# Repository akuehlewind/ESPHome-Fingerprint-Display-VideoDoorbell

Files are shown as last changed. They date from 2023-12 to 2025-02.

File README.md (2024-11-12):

# ESPHome-Doorbell using Aqara G4 inside the case enriched with a Grow R503 fingerprint sensor and 2.8 ILI9341 display

Video doorbell (using Aqara G4) for [Home Assistant](https://www.home-assistant.io) and [ESPHome](https://www.esphome.io). 
It integrates a Grow R503 fingerprint sensor to open a door (in my case a NUKI door lock) via HomeAssistant and additionally I added an ILI9341 display to show some status information like temperature, closed window indicator and most importantly some messages. I can set some messages in a text sensor in HomeAssistant to show them on the display, e.g. to tell the delivery person to just leave the package in the garage. The Aqara is independent of the fingerprint and the display and is only integrated into the housing to make it look nice. The Aqara G4 is simply added via Homekit.

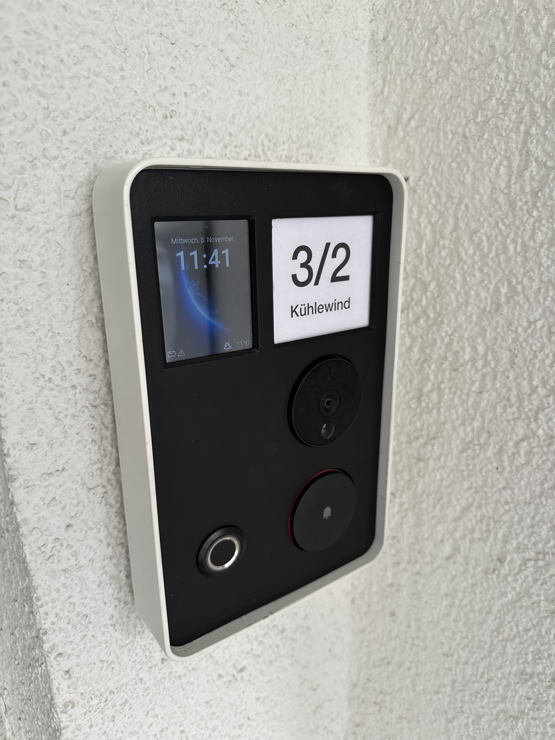
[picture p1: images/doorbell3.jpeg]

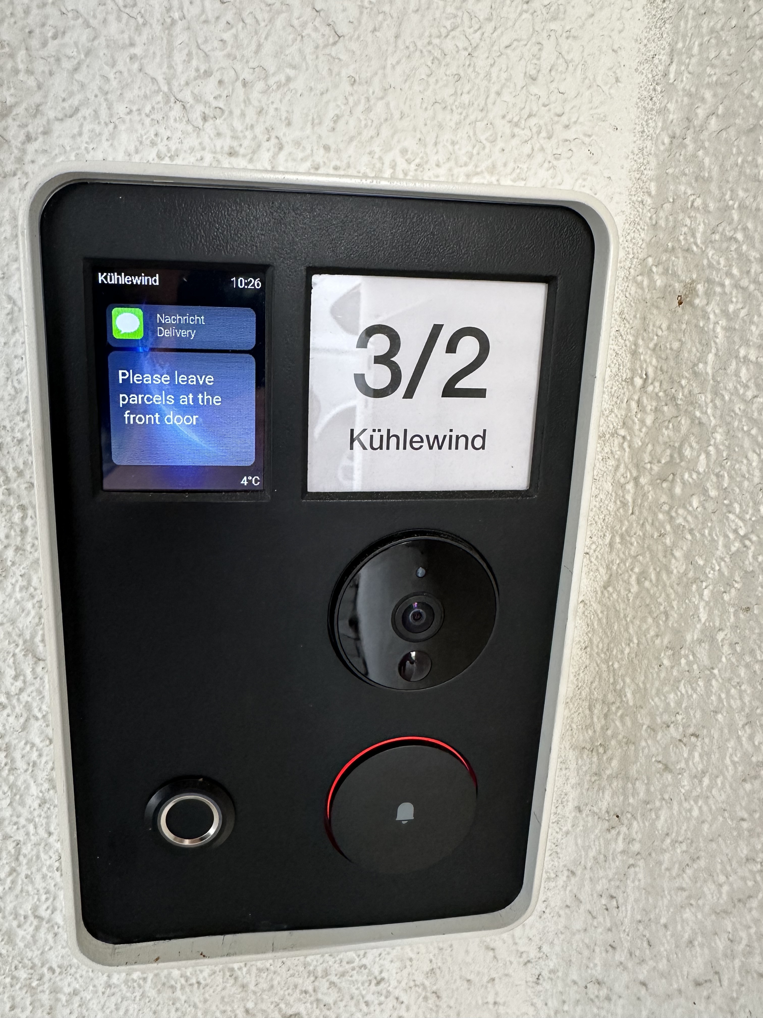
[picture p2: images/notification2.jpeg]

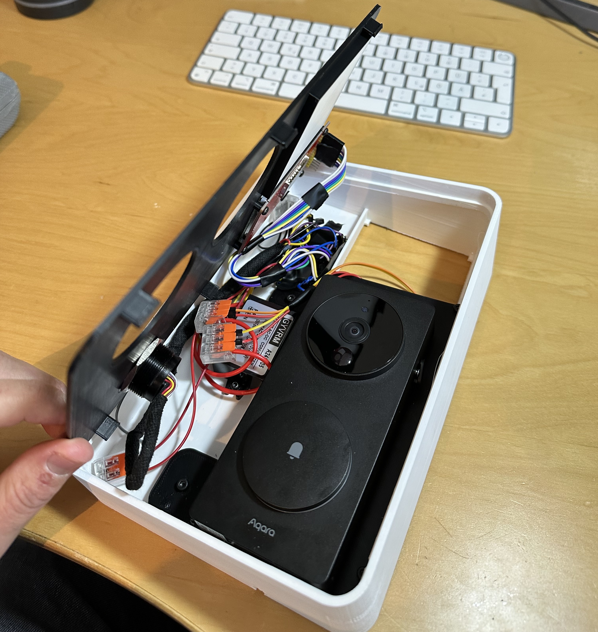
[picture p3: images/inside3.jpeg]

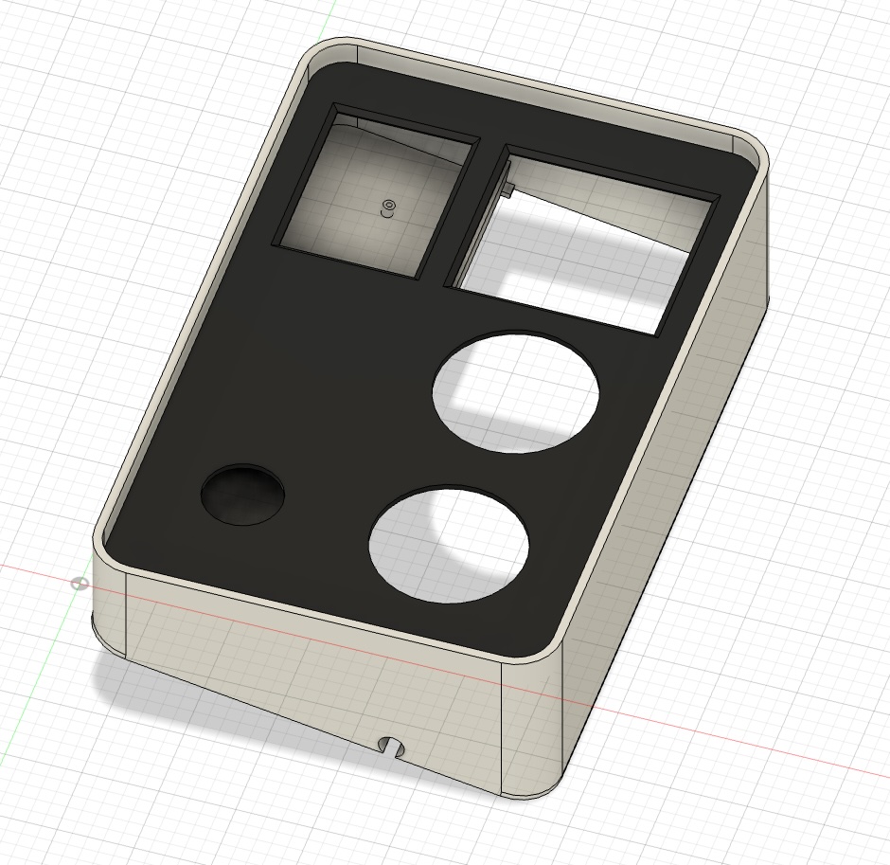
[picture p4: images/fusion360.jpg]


### Features:

- Aqara G4 Videodoorbell as doorbell which I integrated in the case
- Fingerprint Sensor Grow R503 to trigger actions like door opening or you can use it as doorbell
- Display to show some status infos and messages
- Using [ESPHome](https://www.esphome.io) which makes it easy to code and modify for your needs

## Parts needed

| Part | Price | Comment |
|---|---|---|
| Aqara G4 | 90$ | Aqara G4 Homekit Cam |
| Grow R503 | 15$ | Get one from AliExpress 					 |
| ILI9341					 | 15$ | 2.8" 					 |
| ACDC Converter (in my case)  | 5$ | I had some 15V AC wire available so I used an ACDC converter to run the ESP with 5V |

## How
- Flash your ESP32 via ESPHome and use the yaml from the esphome folder. Adjust to your needs
- Print the parts. 
- Use a few screws to attach the display and the Aqara Mount Plate
- Solder the connections or just use some pin connectors and WAGO connectors
- Assemble 

## HomeAssistant
- Create some helpers in home assistant with the following types

| ID | Type | Comment |
|---|---|---|
| input_text.doorbell_text | text | Notification text. Use "," to terminate each line ie. "Leave parcels,outside," (set value without quotation marks)|
| input_text.doorbell_headline | text | Headline of notification. |
| input_text.doorbell_subheadline | text | Sub-Headline of notification. |
| input_boolean.doorbell_display_mailbox_notification | switch  | Doorbell Display Mailbox Notification |

## Connections
Follow the connection diagram, which shows how to put everything together.

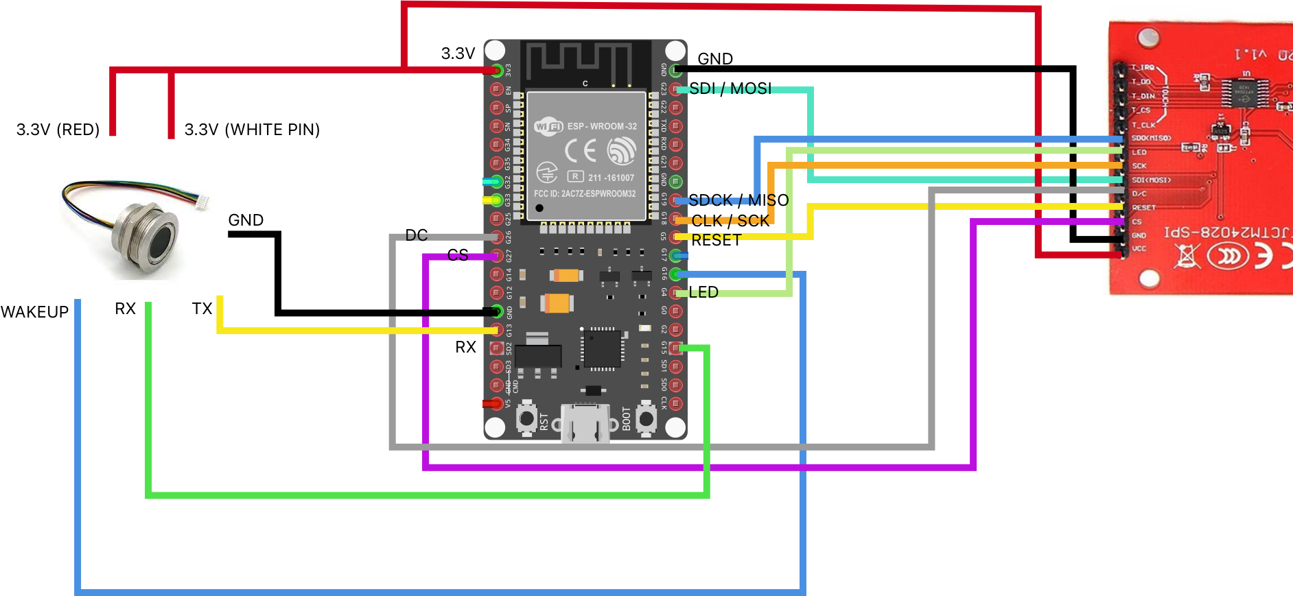
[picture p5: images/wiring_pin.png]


| Glow R5 | PIN  ESP32 | Comment |
|---|---|---|
| TX | G13 | Yellow (RX & TX are twisted) |
| RX | G15 | Green (RX & TX are twisted) 	 |
| GND 					 | GND | Obvious 					 |
| WAKEUP | G16 | Sensing PIN |
| 3.3V | 3.3V | Red |
| 3.3VT | 3.3V | White |

| ILI9341 | PIN  ESP32 | Comment |
|---|---|---|
| CS | G27 | CS |
| D/C | G26 | DC |
| RESET | G5 | RESET |
| SCK | G18 | Clock PIN, CLK |
| SDI (MOSI) | G23 | SDI |
| SDOK (MISO) | G19 | SDOK (MISO) |
| LED | G4 | LED Backlight |
| GND | GND | Ground |
| VCC | 3.3V | Power |\

## 3D Print
See folder print to get all SLT files and the fusion360 file. Feel free to adjust and remix\

# DISCLAIMER
This project is to be considered as a work in progress. 
In my case I have a Siedle doorbell mounted outside and its not my house - so the case has some cut out on the backside that just fits perfectly over the existing Sidle doorbell.
So I just covered the old doorbell and used the power connection from it. As doorbell I now use the Aqara G4 (Homekit) and just added the fingerprint and display for fun to enter my house and show some messages.
Feel free to adjust and remix the 3D cover to your needs. Its designed in Fusion 360 (see folder fusion360)

## Other
Example screenshot of notification



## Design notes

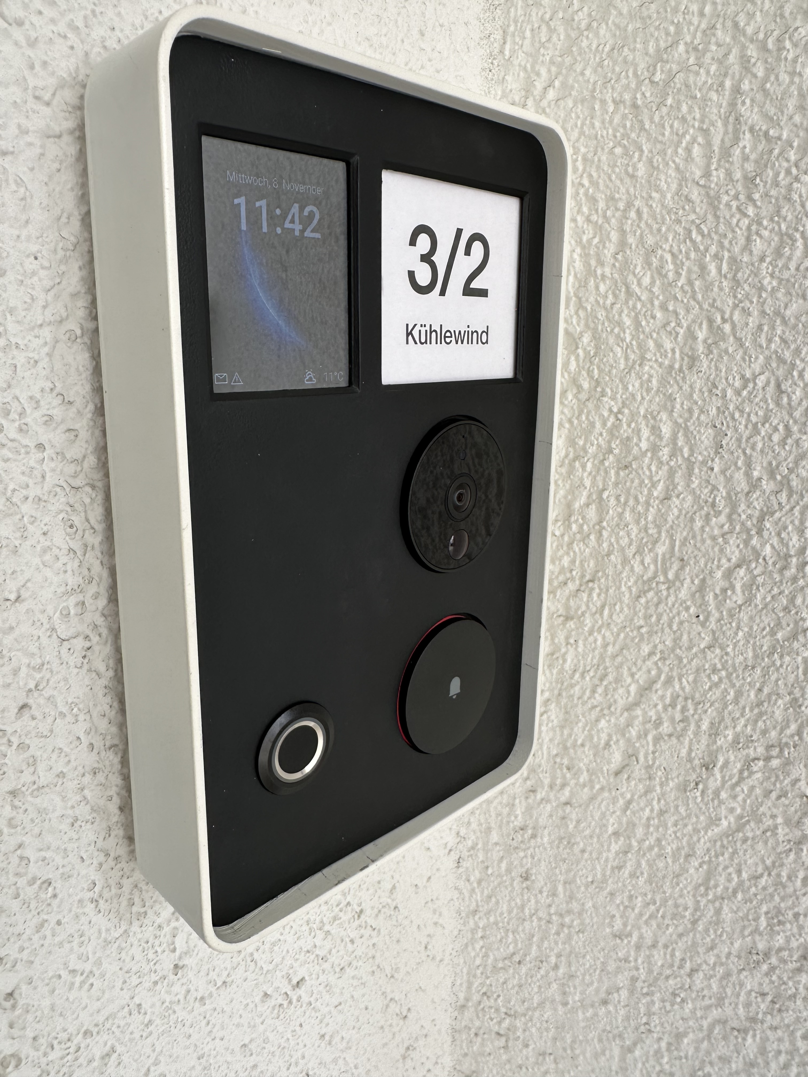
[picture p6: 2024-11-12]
images/doorbell2.jpeg

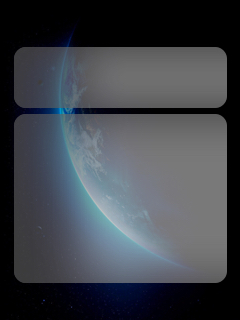
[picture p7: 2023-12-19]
esphome/images/doorbell-background-notification.jpg

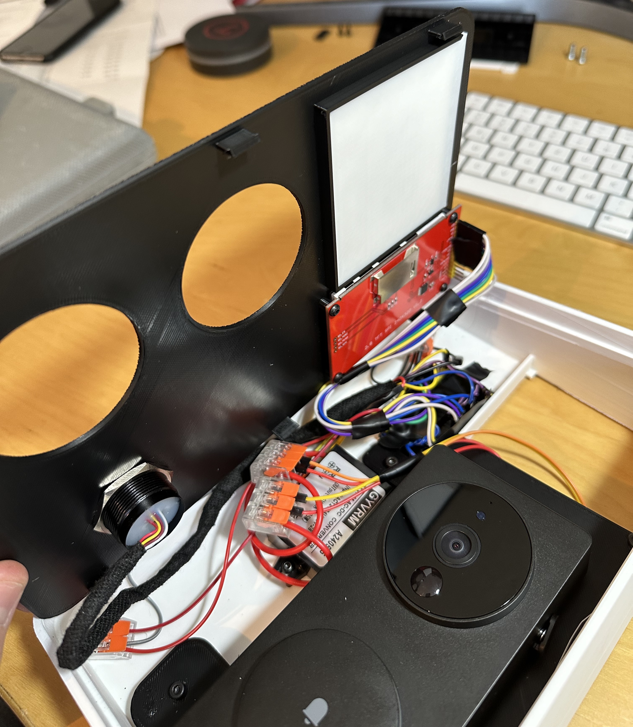
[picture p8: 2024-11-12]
images/inside2.jpeg

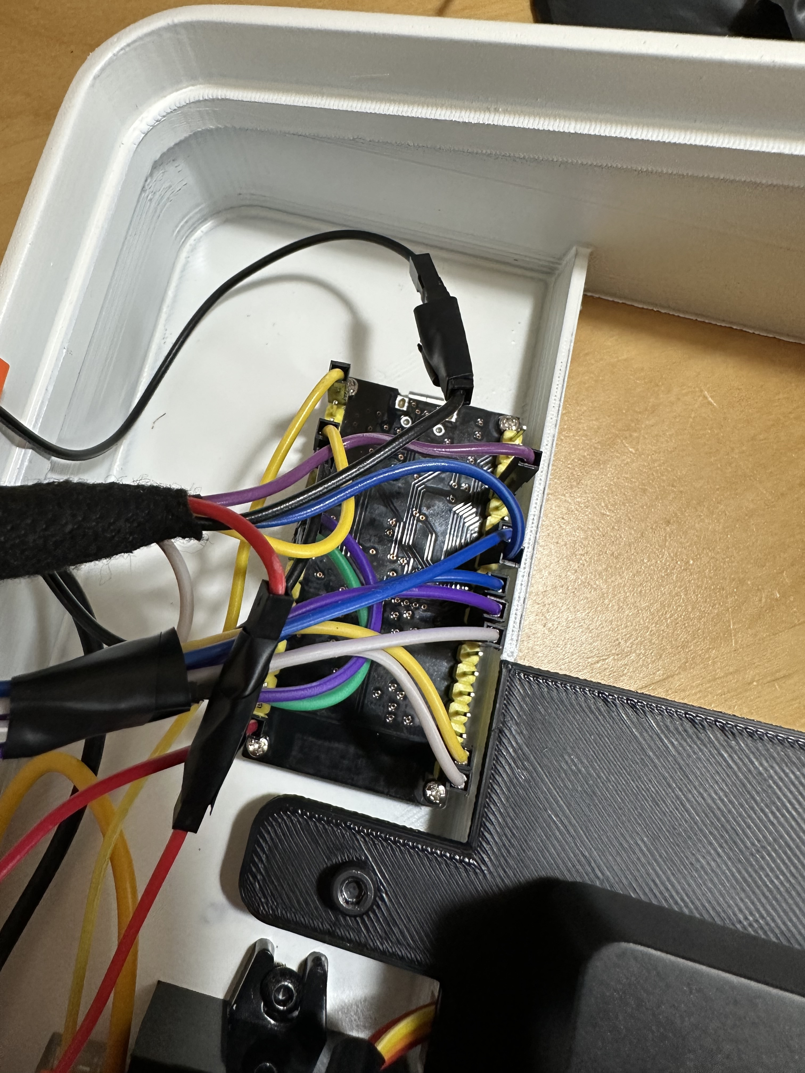
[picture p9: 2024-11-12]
images/esp32.jpeg

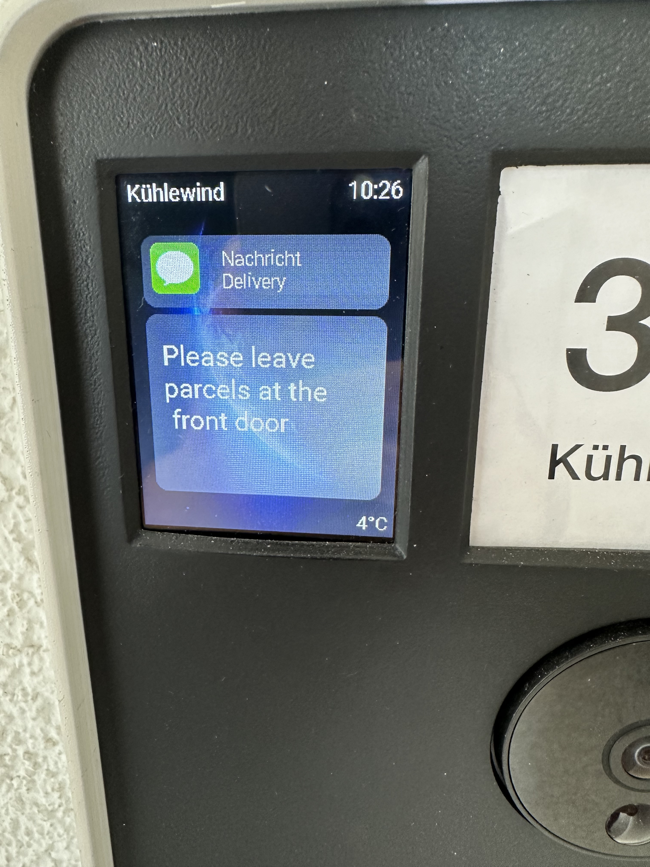
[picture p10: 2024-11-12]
images/notification3.jpeg

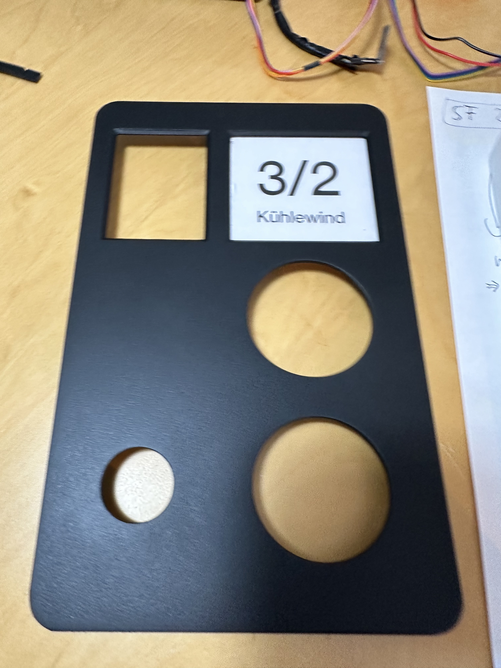
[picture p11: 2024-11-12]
images/frontcover.jpeg

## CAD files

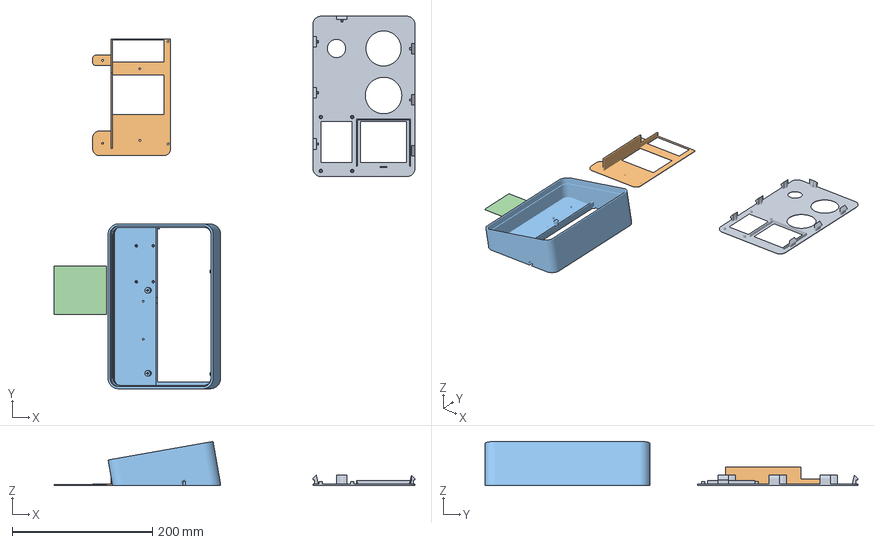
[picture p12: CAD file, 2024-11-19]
3d_print/case.3mf
514.3 x 530.9 x 62.9 mm
cover.stl
aqara-mount-plate.stl
case.stl
sign-backplate.stl

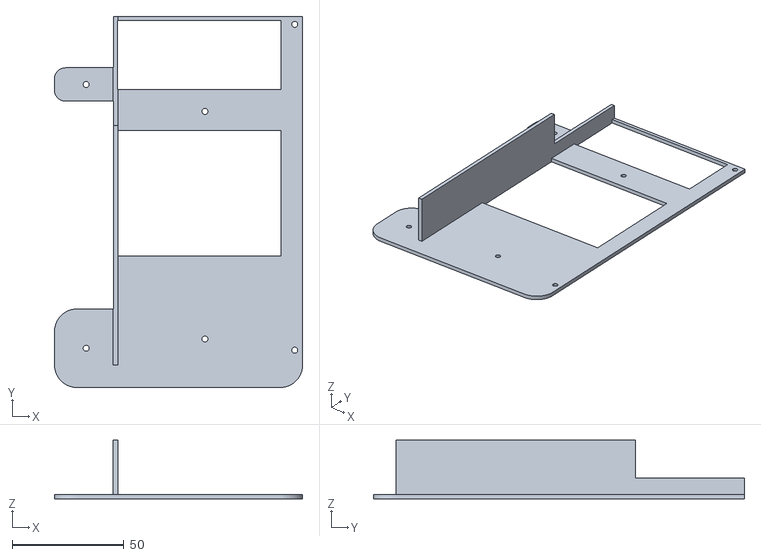
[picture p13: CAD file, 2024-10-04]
3d_print/aqara-mount-plate.stl
111.3 x 166.3 x 26.3

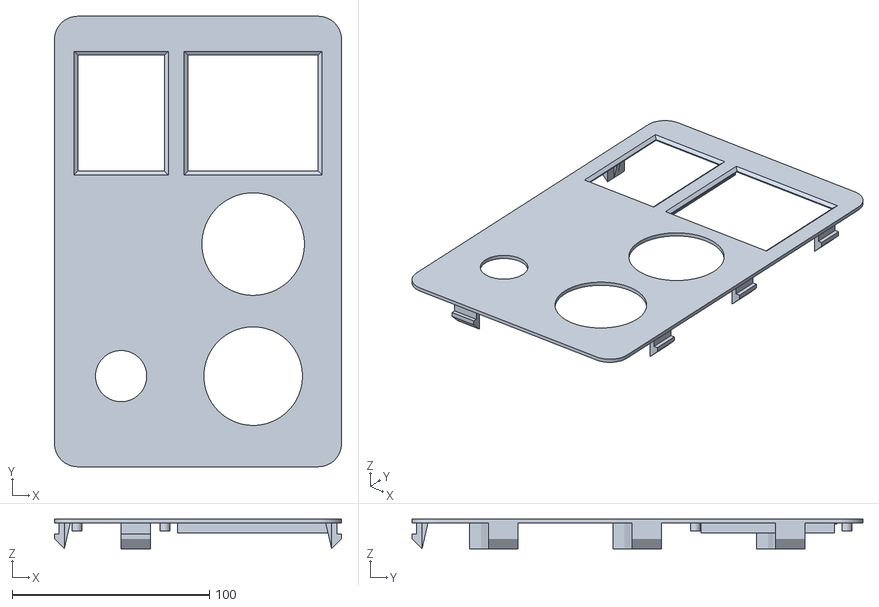
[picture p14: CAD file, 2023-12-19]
3d_print/cover.stl
145.6 x 228.6 x 15.0

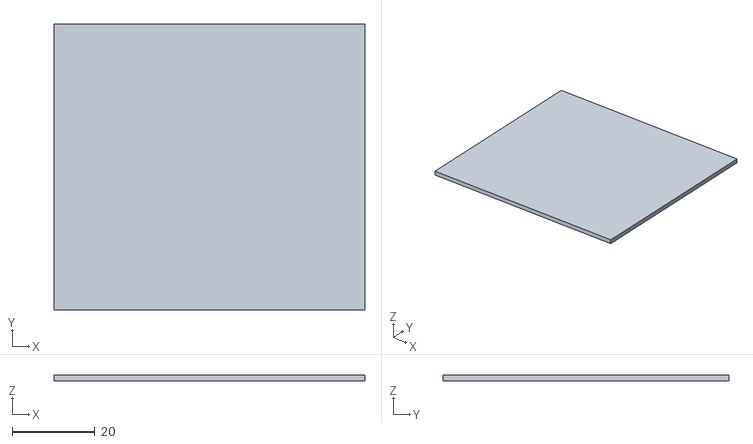
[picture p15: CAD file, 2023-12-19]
3d_print/sign-backplate.stl
75.0 x 69.0 x 1.50

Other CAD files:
3d_print/Doorbell-Fingerprint-AqaraG4.f3d
3d_print/case.stl

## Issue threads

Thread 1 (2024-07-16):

How add fingerprints

pasparakis, 2024-07-16:
Hello,thank you for your project!
i have completed everything..but i don't know how to save a fingerprint
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

akuehlewind, 2024-07-16:
In HomeAssistant go to developer tools -> serices and look for a service called "ESPHome: fingerprint_display_enroll" (or similar". Set a finger_id (any number as id for the finger) and execute. Now place the finger multiple times on the sensor till the finger is scanned. The sensor gets back to normal mode after scan is complete.

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

pasparakis, 2024-07-16:
Thank you for your answer!

I will look for it ..one more question: to open a door I only need to change the entity id in your configuration in this part?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

akuehlewind, 2024-07-16:
This entity is only to show the garage door status on the display as an icon. To open and close using the fingerprint sensor simply add an automation to HA using the state front the fingerprint entity. So if state changes to „Authorized Finger“ then trigger whatever you want

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

pasparakis, 2024-07-18:
Hello!

I've been working for the last few days and I think everything is working!!
I can't find the way to to show the notification..

i created helpers according to your description but nothing is displayed on the screen.

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

akuehlewind, 2024-07-18:
Did you set a value for the text in the helper for "input_text.doorbell_text". According to the code I'm using for the display in esphome it should change the page to show the notification page according to if the text is empty or not.

`- platform: homeassistant
    id: doorbell_text
    entity_id: input_text.doorbell_text
    internal: true
    on_value:
      then:
        - display.page.show: !lambda |-
            if (id(doorbell_text).state != "") {
              return notification_page;
            }
            else{
              return lockscreen_page;
            }
`

pasparakis, 2024-07-18:
I understand..where I have marked, should I put the text that will be shown on the screen?
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

akuehlewind, 2024-07-18:
yes. You don't need quotation marks, just enter the text and put a comma as a line break. I'm not sure if the quotation marks are a problem. Last char has to be a comma otherwise the line is not shown for now. Feel tree to improve the parsing in esphome script :-D

pasparakis, 2024-07-18:
i tried but no success..

I think everything is fine..I can't find the reason why it doesn't display the message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

pasparakis, 2024-07-25:
Final photo:
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

Thank you for your project!

all that remains is to put the Greek language in the code..could you help me?

Closed 2024-09-03.

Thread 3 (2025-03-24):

enrolling etc

mcmasterp, 2025-03-24:
Fantastic work, thank you very much. I am adapting it for a small oled display!

I got it up and going with things but I don't know how to initiate things like enroll and delete? If I missed it in my searching please excuse me and share a link.

mcmasterp, 2025-03-24:
Spoke to soon maybe. I see from google searching that I can use developer tools to do the enrolling and deleting etc. is there a way  to bring that into the device integration screen with all the other entities?

akuehlewind, 2025-03-24:
Yes thats the way to enroll new fingerprints. I guess you can create an automation in HA to start the enroll service and use an input helper variable for the id. Then you use an entity switch or touch action to start the automation as trigger.

Closed 2025-03-24.

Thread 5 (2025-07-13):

Display Problem mit ESP32-2432S028

DobnDiegoGER, 2025-07-13:
Hi,
vor weg Mega Projekt, danke.

Ich wollte dein Projekt mit dem ESP32-2432S028 realisieren. habe soweit einiges geschafft jedoch stolpere ich an der config vom Display.

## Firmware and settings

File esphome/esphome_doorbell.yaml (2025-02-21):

esphome:
  name: fingerprint-display
  friendly_name: fingerprint-display
  includes:
    - includes/doorbell-display.h


esp32:
  board: esp32dev
  framework:
    type: arduino

logger:

ota:
  - platform: esphome  
    password: "XXXXXXXXXXXXXXXXXXXXXX"

wifi:
  ssid: !secret wifi_ssid
  password: !secret wifi_password

time:
  - platform: homeassistant
    id: homeassistant_time
    on_time:
      - seconds: 0
        minutes: /1 # Update every minute
        then:
          - component.update: my_display 

font: 
  # gfonts://family[@weight]
  - file: "gfonts://Roboto@500"
    id: big_text
    size: 60
    glyphs:
      ['&', '@', '!', ',', '.', '?', '"', '%', '(', ')', '+', '-', '_', ':', '°', '0',
       '1', '2', '3', '4', '5', '6', '7', '8', '9', 'A', 'B', 'C', 'D', 'E',
       'F', 'G', 'H', 'I', 'J', 'K', 'L', 'M', 'N', 'O', 'P', 'Q', 'R', 'S',
       'T', 'U', 'V', 'W', 'X', 'Y', 'Z', ' ', 'a', 'b', 'c', 'd', 'e', 'f',
       'g', 'h', 'i', 'j', 'k', 'l', 'm', 'n', 'o', 'p', 'q', 'r', 's', 't',
       'u', 'v', 'w', 'x', 'y', 'z','å', 'Ä', 'ä', 'Ö', 'ö', 'Ü', 'ü', '/']

  # gfonts://family[@weight]
  - file: "gfonts://Roboto@400"
    id: bar_text
    size: 18
    glyphs:
      ['&', '@', '!', ',', '.', '?', '"', '%', '(', ')', '+', '-', '_', ':', '°', '0',
       '1', '2', '3', '4', '5', '6', '7', '8', '9', 'A', 'B', 'C', 'D', 'E',
       'F', 'G', 'H', 'I', 'J', 'K', 'L', 'M', 'N', 'O', 'P', 'Q', 'R', 'S',
       'T', 'U', 'V', 'W', 'X', 'Y', 'Z', ' ', 'a', 'b', 'c', 'd', 'e', 'f',
       'g', 'h', 'i', 'j', 'k', 'l', 'm', 'n', 'o', 'p', 'q', 'r', 's', 't',
       'u', 'v', 'w', 'x', 'y', 'z','å', 'Ä', 'ä', 'Ö', 'ö', 'Ü', 'ü', '/']

  # gfonts://family[@weight]
  - file: "gfonts://Roboto@400"
    id: notification_text
    size: 25
    glyphs:
      ['&', '@', '!', ',', '.', '?', '"', '%', '(', ')', '+', '-', '_', ':', '°', '0',
       '1', '2', '3', '4', '5', '6', '7', '8', '9', 'A', 'B', 'C', 'D', 'E',
       'F', 'G', 'H', 'I', 'J', 'K', 'L', 'M', 'N', 'O', 'P', 'Q', 'R', 'S',
       'T', 'U', 'V', 'W', 'X', 'Y', 'Z', ' ', 'a', 'b', 'c', 'd', 'e', 'f',
       'g', 'h', 'i', 'j', 'k', 'l', 'm', 'n', 'o', 'p', 'q', 'r', 's', 't',
       'u', 'v', 'w', 'x', 'y', 'z','å', 'Ä', 'ä', 'Ö', 'ö', 'Ü', 'ü', '/']       

  # gfonts://family[@weight]
  - file: "gfonts://Roboto@300"
    id: notice_text
    size: 16
    glyphs:
      ['&', '@', '!', ',', '.', '?', '"', '%', '(', ')', '+', '-', '_', ':', '°', '0',
       '1', '2', '3', '4', '5', '6', '7', '8', '9', 'A', 'B', 'C', 'D', 'E',
       'F', 'G', 'H', 'I', 'J', 'K', 'L', 'M', 'N', 'O', 'P', 'Q', 'R', 'S',
       'T', 'U', 'V', 'W', 'X', 'Y', 'Z', ' ', 'a', 'b', 'c', 'd', 'e', 'f',
       'g', 'h', 'i', 'j', 'k', 'l', 'm', 'n', 'o', 'p', 'q', 'r', 's', 't',
       'u', 'v', 'w', 'x', 'y', 'z','å', 'Ä', 'ä', 'Ö', 'ö', 'Ü', 'ü', '/']     

  - file: 'gfonts://Material+Symbols+Outlined@100'
    id: materialdesign_icons_25
    size: 25
    glyphs: ["\U0000e0be","\U0000e82d","\U0000e002"]

  - file: 'fonts/materialdesignicons-webfont.ttf' // Get them from https://github.com/Templarian/MaterialDesign-Webfont/blob/master/fonts/materialdesignicons-webfont.ttf and copy to a folder /fonts
    id: weather_icons
    size: 25
    glyphs: [
      "\U000F0590", # mdi-weather-cloudy
      "\U000F0F2F", # mdi-weather-cloudy-alert
      "\U000F0E6E", # mdi-weather-cloudy-arrow-right
      "\U000F0591", # mdi-weather-fog
      "\U000F0592", # mdi-weather-hail
      "\U000F0F30", # mdi-weather-hazy
      "\U000F0898", # mdi-weather-hurricane
      "\U000F0593", # mdi-weather-lightning
      "\U000F067E", # mdi-weather-lightning-rainy
      "\U000F0594", # mdi-weather-night
      "\U000F0F31", # mdi-weather-night-partly-cloudy
      "\U000F0595", # mdi-weather-partly-cloudy
      "\U000F0F32", # mdi-weather-partly-lightning
      "\U000F0F33", # mdi-weather-partly-rainy
      "\U000F0F34", # mdi-weather-partly-snowy
      "\U000F0F35", # mdi-weather-partly-snowy-rainy
      "\U000F0596", # mdi-weather-pouring
      "\U000F0597", # mdi-weather-rainy
      "\U000F0598", # mdi-weather-snowy
      "\U000F0F36", # mdi-weather-snowy-heavy
      "\U000F067F", # mdi-weather-snowy-rainy
      "\U000F0599", # mdi-weather-sunny
      "\U000F0F37", # mdi-weather-sunny-alert
      "\U000F14E4", # mdi-weather-sunny-off
      "\U000F059A", # mdi-weather-sunset
      "\U000F059B", # mdi-weather-sunset-down
      "\U000F059C", # mdi-weather-sunset-up
      "\U000F0F38", # mdi-weather-tornado
      "\U000F059D", # mdi-weather-windy
      "\U000F059E" # mdi-weather-windy-variant
      ]

image:
  - file: "images/doorbell-background-plain.jpg"
    id: background
    type: RGB
    transparency: alpha_channel
    #resize: 240x320    
  - file: "images/doorbell-background-notification.jpg"
    id: notification
    type: RGB  
    transparency: alpha_channel
  - file: "images/doorbell-message-icon.png"
    id: message_icon 
    type: RGB
    transparency: alpha_channel
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

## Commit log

2023-12-19 Videodoorbell Aqara G4 with fingerprint Grow R503 and 2.8 ILI9341 display
    [Doorbell-Fingerprint-AqaraG4.f3d, aqara-mount-plate.stl, case.stl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]
2023-12-19 wrong type for mailbox switch in readme
2024-10-04 modified mount plate
    [Doorbell-Fingerprint-AqaraG4.f3d, aqara-mount-plate.stl]
2024-11-02 replaced update_interval: 10s with update on state or value change
    [esphome_doorbell.yaml]
2024-11-19 added files for bambu studio
    [case.3mf]
2025-02-21 replace type RGBA with type: RGB and transparency: alpha_channel for ESPHome 2025.2.0
    [esphome_doorbell.yaml]
